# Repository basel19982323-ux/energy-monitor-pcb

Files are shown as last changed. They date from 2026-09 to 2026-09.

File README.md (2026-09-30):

# ESP32-C3 Solar Energy Monitor (PCB)

A 2-layer, 60 × 38 mm board that measures the **voltage, current and power** of a 50 W / 12 V solar panel and reports them over **Wi-Fi**.

> **Status:** designed and checked in KiCad 10 (ERC 0 errors, DRC 0 errors, 0 unconnected). **Not yet fabricated or tested on hardware.** Firmware is not part of this repository yet.

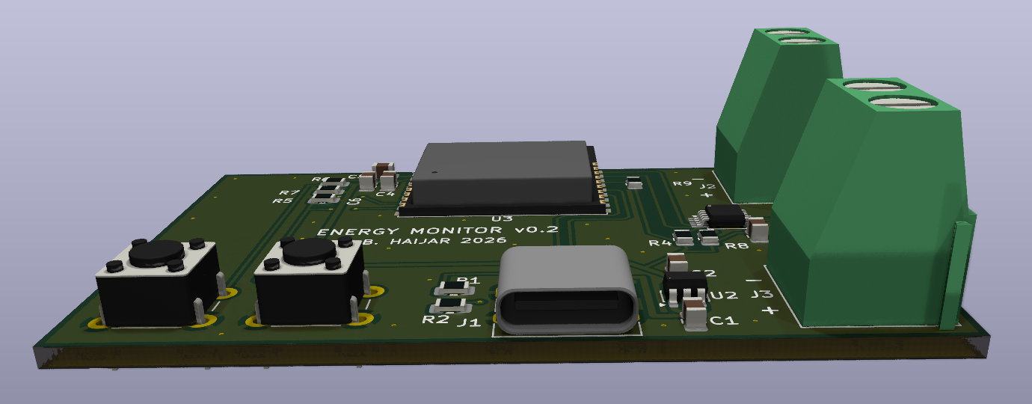
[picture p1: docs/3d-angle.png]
3D render of the board


| Top | Bottom |
|---|---|
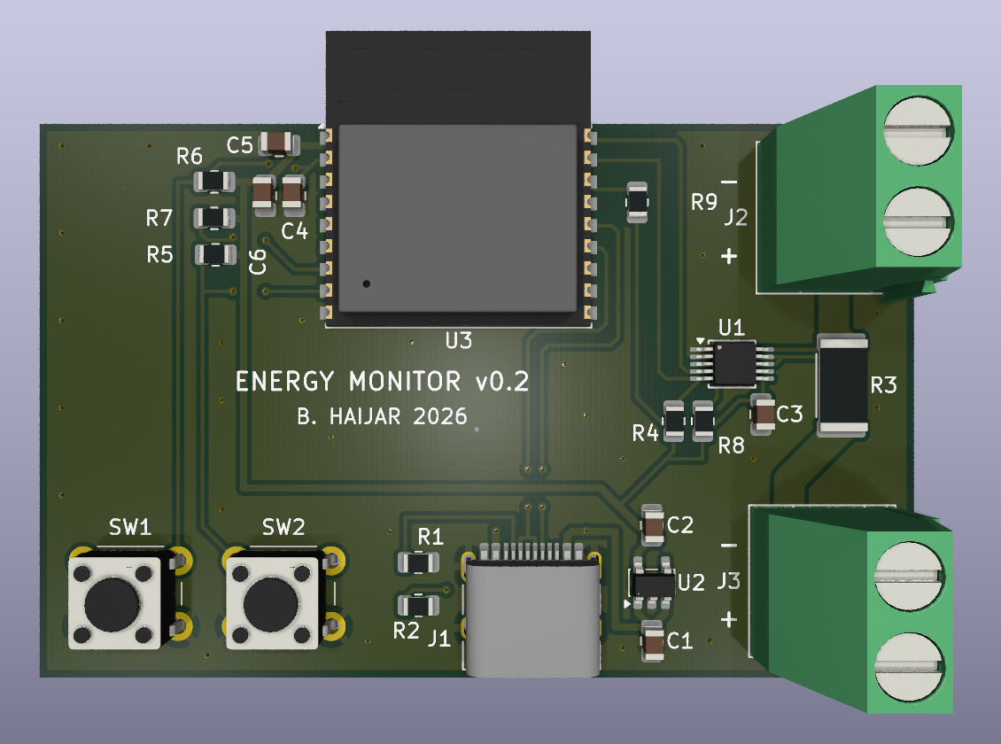
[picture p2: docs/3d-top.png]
Top view
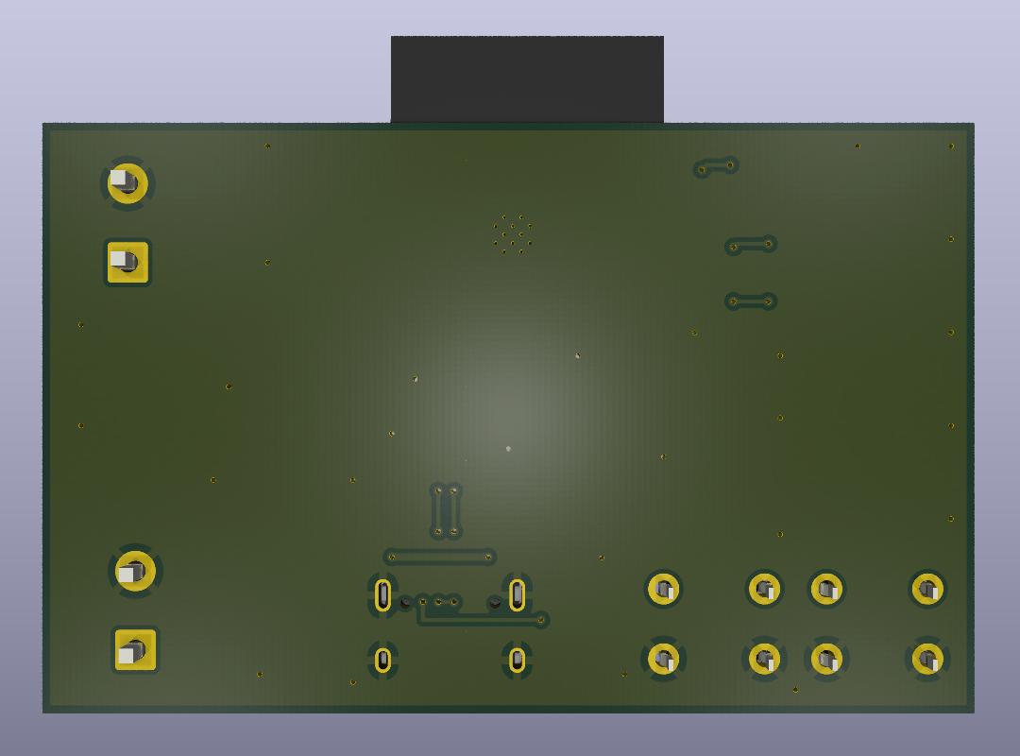
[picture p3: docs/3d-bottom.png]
Bottom view
|  |  |

---

## What it does

The panel's current flows through the board, from **J2 (Solar IN)** to **J3 (Load OUT)**, through a small 20 mΩ shunt resistor. The board works in five steps:

1. **Feed:** 5 V comes in through USB-C (J1). R1/R2 (5.1 kΩ on CC1/CC2) tell the USB source that this is a 5 V sink.
2. **Clean:** an AP2112K-3.3 LDO regulator (U2) makes a steady 3.3 V supply.
3. **Measure:** an INA226 (U1) measures the panel voltage and the current through the 20 mΩ shunt (R3).
4. **Think:** an ESP32-C3-WROOM-02 module (U3) reads the INA226 over I²C (address 0x40) and calculates power.
5. **Send:** the ESP32-C3 sends the readings over Wi-Fi. USB data (D+/D−) goes to the ESP32-C3's native USB for programming.

## Key numbers

| Item | Value |
|---|---|
| Target panel | 50 W, 12 V (Imp 2.84 A, Isc 3.13 A, Voc 20.8 V) |
| Shunt | 20 mΩ, 2512, 1 %, 2 W, Kelvin-connected |
| Max measurable current | 81.92 mV ÷ 0.02 Ω ≈ **4.1 A** (INA226 full-scale shunt voltage) |
| Shunt power at 4.1 A | 4.1² × 0.02 ≈ 0.34 W (well below the 2 W rating) |
| Logic supply | 5 V USB-C → 3.3 V (AP2112K, 600 mA max) |
| Board | 2 layers, 1.6 mm, 60 × 38 mm |

## Design decisions

- **Trace widths by net class** (IPC-2221): signals 0.25 mm, power (VBUS, +3V3) 0.5 mm, high current (PV_IN, LOAD_OUT) 2.1 mm for ~4 A.
- **Kelvin sensing:** the INA226 sense traces leave from the inner edges of the shunt pads, so the high current does not flow through the measurement traces.
- **Ground:** ground pours on both layers, joined by stitching vias, so every return current has a short path home.
- **Decoupling:** 100 nF + 10 µF placed at the ESP32-C3 3V3 pin (smallest capacitor closest), 100 nF at the INA226, 1 µF at the LDO input and output.
- **Antenna:** the ESP32-C3 antenna overhangs the board edge with no copper underneath, following Espressif's layout guidelines.
- **Boot and reset:** RESET (EN) with an RC start-up delay (10 kΩ + 1 µF), a BOOT button on IO9, and pull-ups on the strapping pins IO2/IO8/IO9.
- **Manufacturing:** checked against JLCPCB's capabilities (0.2 mm clearance, 0.3 mm vias, 0.15 mm silkscreen line width).

## Repository contents

```
hardware/     KiCad 10 project (schematic, PCB, project file)
production/   JLCPCB-ready files: Gerbers + drill (zip), BOM, CPL (positions)
docs/         Schematic PDF, 3D renders, layout preview
```

- **Schematic (PDF):** [docs/energy-monitor.pdf](docs/energy-monitor.pdf)
- **Gerbers + drill:** [production/energy-monitor_v0.2.zip](production/energy-monitor_v0.2.zip)
- **BOM** (with LCSC part numbers): [production/energy-monitor_v0.2_bom.csv](production/energy-monitor_v0.2_bom.csv)
- **CPL / pick-and-place:** [production/energy-monitor_v0.2_positions.csv](production/energy-monitor_v0.2_positions.csv)

## Bill of materials (summary)

| Ref | Part | LCSC |
|---|---|---|
| U1 | TI INA226AIDGSR (current/power monitor) | C49851 |
| U2 | Diodes AP2112K-3.3TRG1 (3.3 V LDO) | C51118 |
| U3 | Espressif ESP32-C3-WROOM-02-N4 | C2934560 |
| J1 | HRO TYPE-C-31-M-12 (USB-C) | C165948 |
| J2, J3 | Phoenix MKDS 1,5/2-5,08 terminal block | C480516 |
| R3 | 20 mΩ 2512 2 W shunt | C5375423 |
| SW1, SW2 | Omron B3F-1020 tactile switch | C722171 |
| R, C | 0805 passives (see BOM) | — |

## Notes

- The 3D model of the USB-C connector is not included (it is not from the official KiCad library), so J1 appears without a body in the 3D viewer. The PCB and fabrication files are not affected.
- Next steps: order the boards, write the ESP32-C3 firmware (read the INA226, publish over Wi-Fi), and test against a reference meter.

## Tools

KiCad 10 · JLCPCB design rules · Fabrication Toolkit plugin

## License

Hardware design licensed under the **CERN Open Hardware Licence v2 – Permissive** ([CERN-OHL-P-2.0](LICENSE)).

© 2026 Basel Haijar

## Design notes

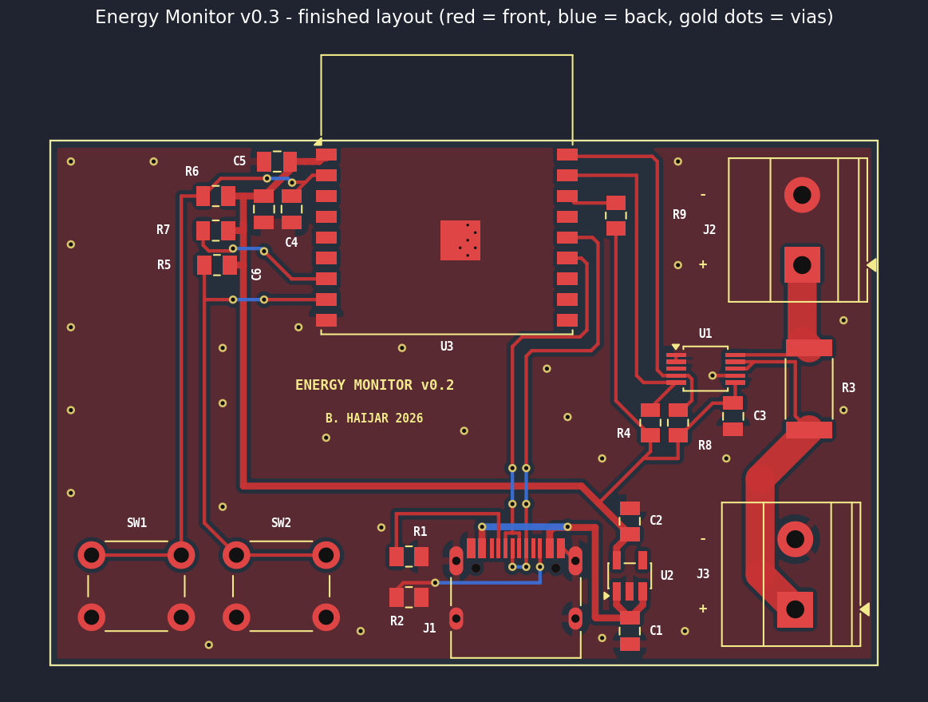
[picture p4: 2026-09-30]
docs/layout-preview.png

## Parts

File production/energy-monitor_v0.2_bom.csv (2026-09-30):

Designator | Footprint | Quantity | Value | LCSC Part #
C1, C2, C4 | 0805 | 3 | 1u | C28323
C3, C5 | 0805 | 2 | 100n | C49678
C6 | 0805 | 1 | 10u | C15850
J1 | USB_C_Receptacle_HRO_TYPE-C-31-M-12 | 1 | USB_C_Receptacle_USB2.0_16P | C165948
J2 | TerminalBlock_Phoenix_MKDS-1,5-2-5.08_1x02_P5.08mm_Horizontal | 1 | Solar_Panel_IN | C480516
J3 | TerminalBlock_Phoenix_MKDS-1,5-2-5.08_1x02_P5.08mm_Horizontal | 1 | Load_OUT | C480516
R1, R2 | 0805 | 2 | 5.1k | C27834
R3 | 2512 | 1 | 20m | C5375423
R4, R8 | 0805 | 2 | 4.7k | C17673
R5, R6, R7, R9 | 0805 | 4 | 10k | C17414
SW1 | SW_PUSH_6mm | 1 | RESET | C722171
SW2 | SW_PUSH_6mm | 1 | BOOT | C722171
U1 | TSSOP-10_3x3mm_P0.5mm | 1 | INA226 | C49851
U2 | SOT-23-5 | 1 | AP2112K-3.3 | C51118
U3 | ESP32-C3-WROOM-02 | 1 | ESP32-C3-WROOM-02 | C2934560

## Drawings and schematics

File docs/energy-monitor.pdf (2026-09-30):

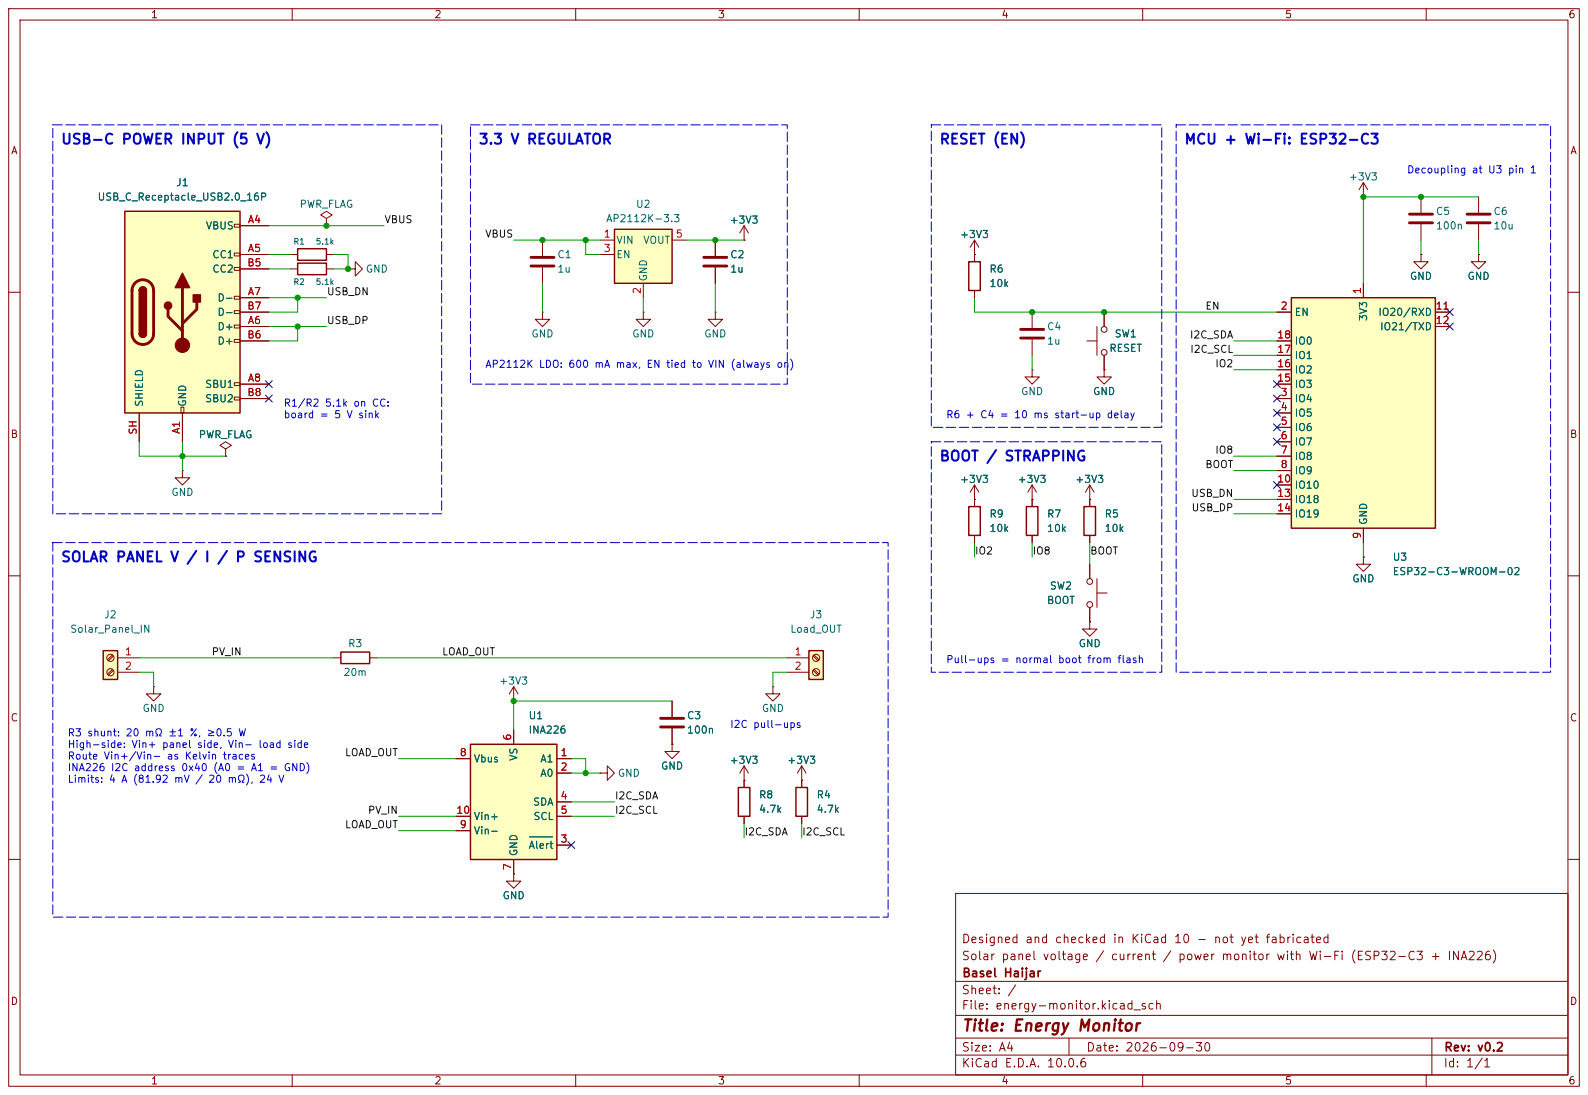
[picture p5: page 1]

Designed and checked in KiCad 10 - not yet fabricated +3V3 GND

AP2112K LDO: 600 mA max, EN tied to VIN (always on)

R6 + C4 = 10 ms start-up delay

INA226 I2C address 0x40 (A0 = A1 = GND) Limits: 4 A (81.92 mV / 20 mΩ), 24 V SOLAR PANEL V / I / P SENSING

Pull-ups = normal boot from flash R3 shunt: 20 mΩ ±1 %, ≥0.5 W

High-side: Vin+ panel side, Vin− load side Route Vin+/Vin− as Kelvin traces

Solar panel voltage / current / power monitor with Wi-Fi (ESP32-C3 + INA226)
Basel Haijar
Sheet: /
File: energy-monitor.kicad_sch
Title: Energy Monitor

Size: A4 | Rev: v0.2
KiCad E.D.A. 10.0.6 | Id: 1/1

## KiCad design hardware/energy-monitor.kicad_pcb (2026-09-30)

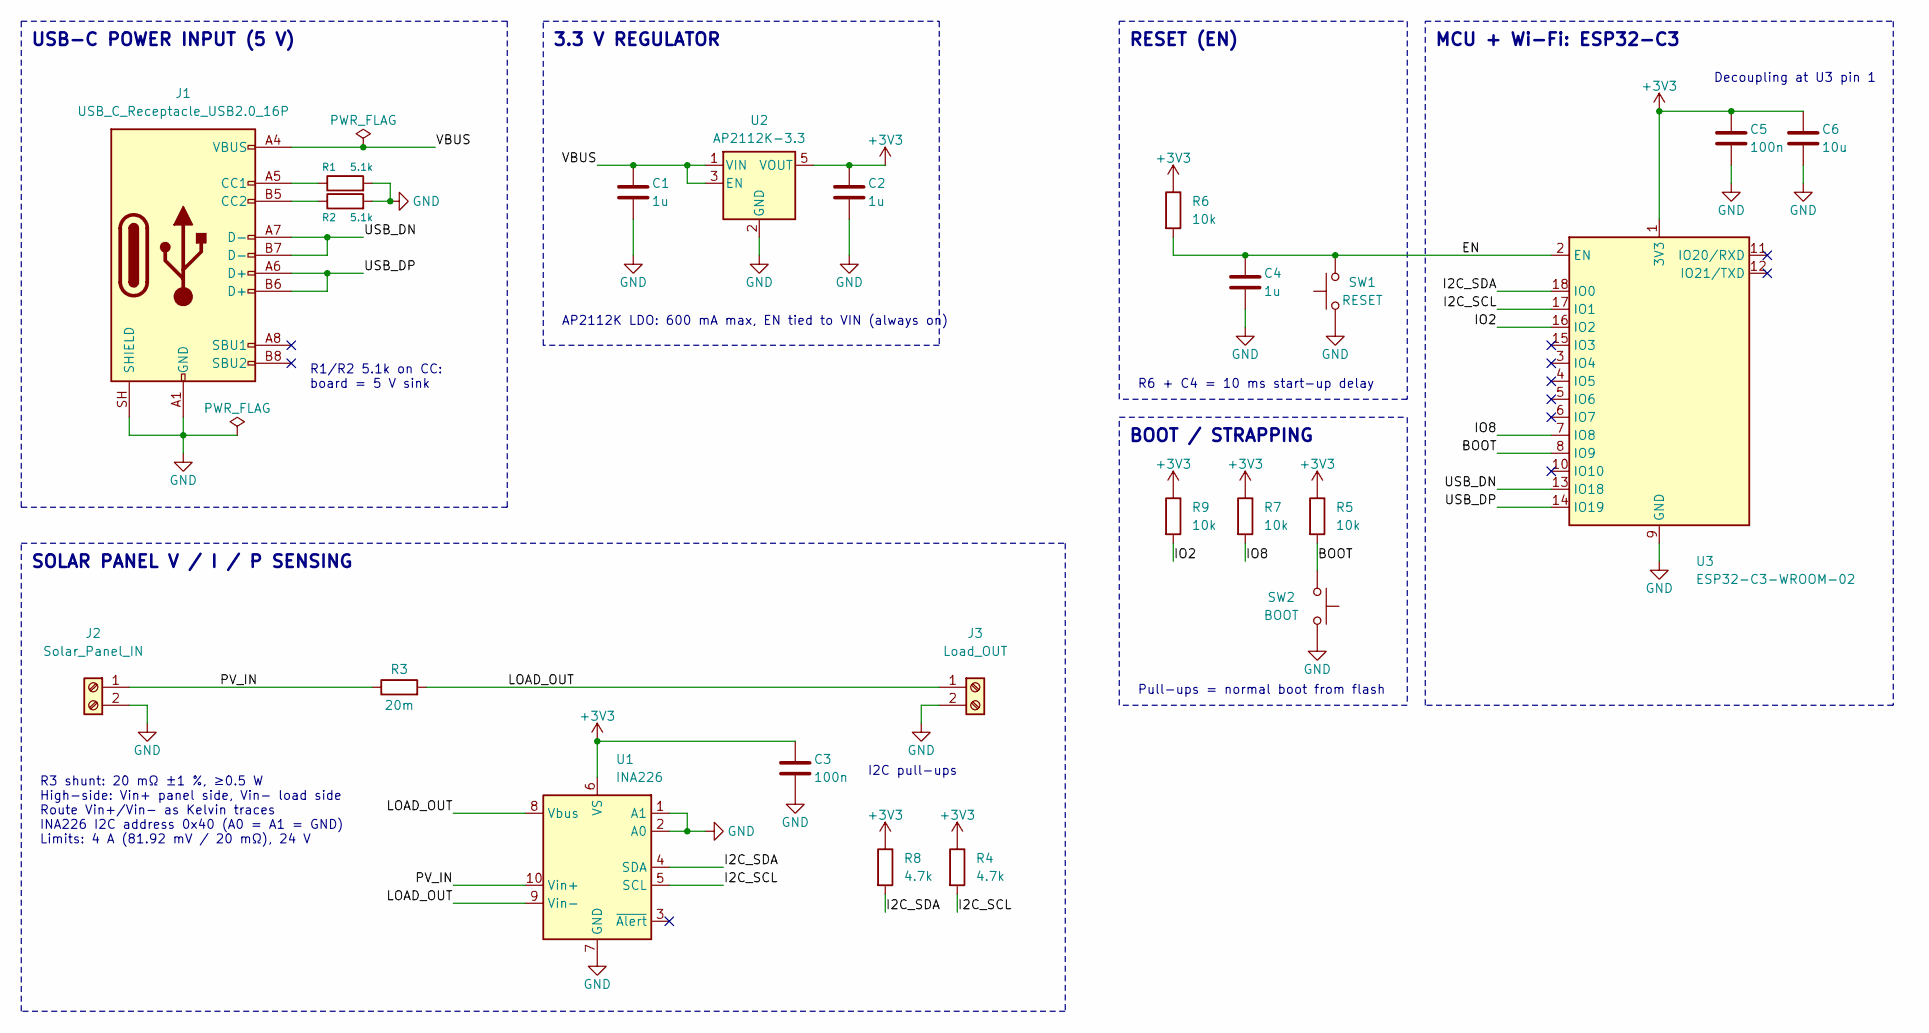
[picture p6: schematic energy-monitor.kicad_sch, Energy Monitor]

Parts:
C1, C2, C4: 1u; C_0805_2012Metric; LCSC C28323
C3, C5: 100n; C_0805_2012Metric; LCSC C49678
C6: 10u; C_0805_2012Metric; LCSC C15850
J1: USB_C_Receptacle_USB2.0_16P; USB_C_Receptacle_HRO_TYPE-C-31-M-12; LCSC C165948
J2: Solar_Panel_IN; TerminalBlock_Phoenix_MKDS-1,5-2-5.08_1x02_P5.08mm_Horizont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; LCSC C480516
J3: Load_OUT; TerminalBlock_Phoenix_MKDS-1,5-2-5.08_1x02_P5.08mm_Horizont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; LCSC C480516
R1, R2: 5.1k; R_0805_2012Metric; LCSC C27834
R3: 20m; R_2512_6332Metric; LCSC C5375423
R4, R8: 4.7k; R_0805_2012Metric; LCSC C17673
R5, R6, R7, R9: 10k; R_0805_2012Metric; LCSC C17414
SW1: RESET; SW_PUSH_6mm; LCSC C722171
SW2: BOOT; SW_PUSH_6mm; LCSC C722171
U1: INA226; TSSOP-10_3x3mm_P0.5mm; LCSC C49851
U2: AP2112K-3.3; SOT-23-5; LCSC C51118
U3: ESP32-C3-WROOM-02; LCSC C2934560

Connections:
+3V3: C2.1, C3.1, C5.1, C6.1, R4.1, R5.1, R6.1, R7.1, R8.1, R9.1, U1.6 (VS), U2.5 (VOUT), U3.1 (3V3)
/BOOT: R5.2, SW2.1, U3.8 (IO9)
/EN: C4.1, R6.2, SW1.2, U3.2 (EN)
/I2C_SCL: R4.2, U1.5 (SCL), U3.17 (IO1)
/I2C_SDA: R8.2, U1.4 (SDA), U3.18 (IO0)
/IO2: R9.2, U3.16 (IO2)
/IO8: R7.2, U3.7 (IO8)
/LOAD_OUT: J3.1, R3.2, U1.8 (Vbus), U1.9 (Vin-)
/PV_IN: J2.1, R3.1, U1.10 (Vin+)
/USB_DN: J1.A7 (D-), J1.B7 (D-), U3.13 (IO18)
/USB_DP: J1.A6 (D+), J1.B6 (D+), U3.14 (IO19)
/VBUS: C1.1, J1.A4 (VBUS), J1.A9 (VBUS), J1.B4 (VBUS), J1.B9 (VBUS), U2.1 (VIN), U2.3 (EN)
GND: C1.2, C2.2, C3.2, C4.2, C5.2, C6.2, J1.A1 (GND), J1.A12 (GND), J1.B1 (GND), J1.B12 (GND), J1.SH (SHIELD), J2.2, J3.2, R1.2, R2.2, SW1.1, SW2.2, U1.1 (A1), U1.2 (A0), U1.7 (GND), U2.2 (GND), U3.9 (GND), U3.19 (GND)
unnamed: J1.A5 (CC1), R1.1
unnamed: J1.B5 (CC2), R2.1

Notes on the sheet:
I2C pull-ups
RESET (EN)
BOOT / STRAPPING
Decoupling at U3 pin 1
R1/R2 5.1k on CC: board = 5 V sink
MCU + Wi-Fi: ESP32-C3
SOLAR PANEL V / I / P SENSING
R3 shunt: 20 mΩ ±1 %, ≥0.5 W High-side: Vin+ panel side, Vin− load side Route Vin+/Vin− as Kelvin traces INA226 I2C address 0x40 (A0 = A1 = GND) Limits: 4 A (81.92 mV / 20 mΩ), 24 V
USB-C POWER INPUT (5 V)
AP2112K LDO: 600 mA max, EN tied to VIN (always on)
Pull-ups = normal boot from flash
3.3 V REGULATOR
R6 + C4 = 10 ms start-up delay

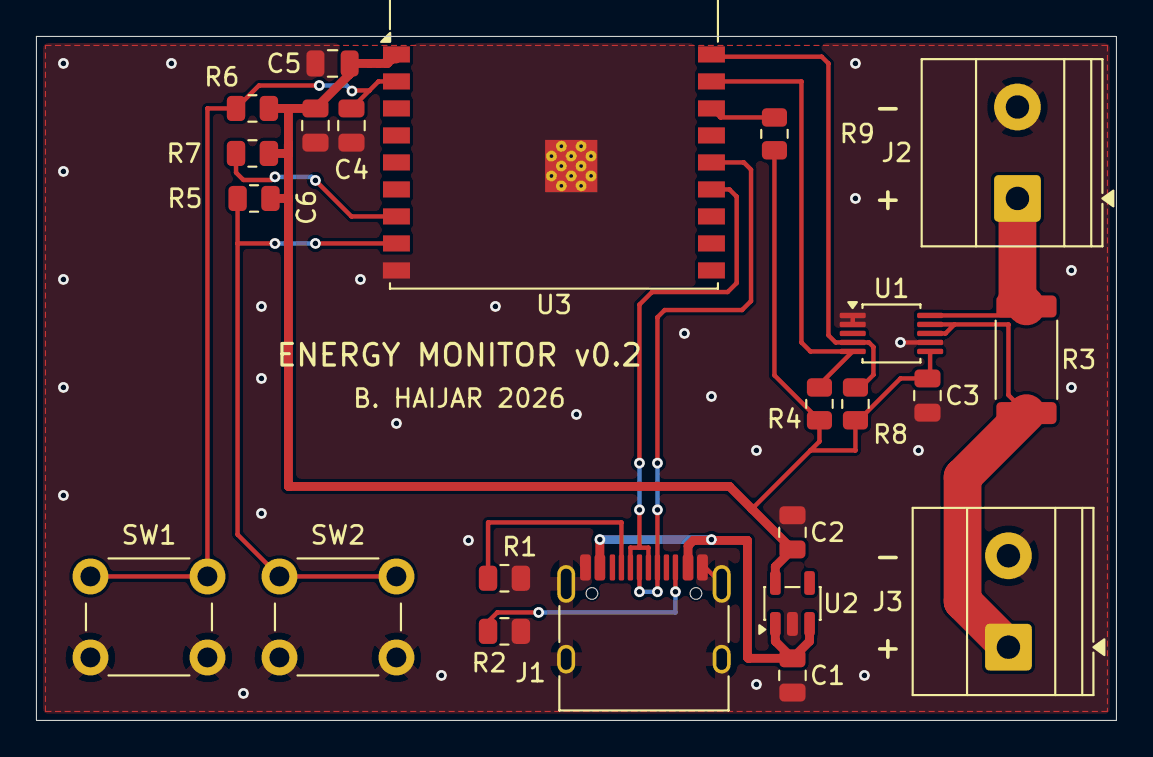
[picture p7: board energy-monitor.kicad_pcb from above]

Board: 2 copper layers, 60.0 x 38.0 mm, 23 parts (0 on the bottom side), 15 nets.

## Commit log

2026-09-30 Add KiCad 10 project (schematic, PCB, project file)
    [energy-monitor.kicad_pcb, energy-monitor.kicad_sch]
2026-09-30 Add JLCPCB production files (Gerbers + drill, BOM, CPL)
    [energy-monitor_v0.2_bom.csv, energy-monitor_v0.2_positions.csv]
2026-09-30 Add schematic PDF, 3D renders and layout preview
2026-10-19 Add ESP32-C3 firmware (ESP-IDF): INA226 readings, latched alarms, Wi-Fi/MQTT
    - INA226 driver over I2C with calibration (CAL = 2048, 125 uA/bit) and
    automatic re-calibration after the sensor recovers
    - Latched alarm on overcurrent, overvoltage and missing sensor; BOOT button reset
    - JSON telemetry over Wi-Fi + MQTT
    - Wokwi simulation files and a simulated INA226 custom chip
    - 9 simulation tests documented in firmware/README.md
